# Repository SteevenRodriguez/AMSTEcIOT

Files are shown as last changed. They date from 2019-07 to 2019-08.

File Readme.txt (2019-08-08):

Integrantes: 
•	Nécker Iván Espinosa Feijoo
•	Sophia Denisse Gómez Quimí
•	Steeven Joshua Rodríguez Alvarado
•	Jonathan Oswaldo Yagual Peredo
Título del proyecto: Clasificador de objetos mediante peso
Descripción del proyecto: El clasificador de objetos deberá identificar que objeto está encima de la plataforma, conociendo su peso. Para ello se requiere aplicar machine learning. Esta información debe ser registrada y enviada a la nube para luego ser mostrada por la aplicación desarrollada.

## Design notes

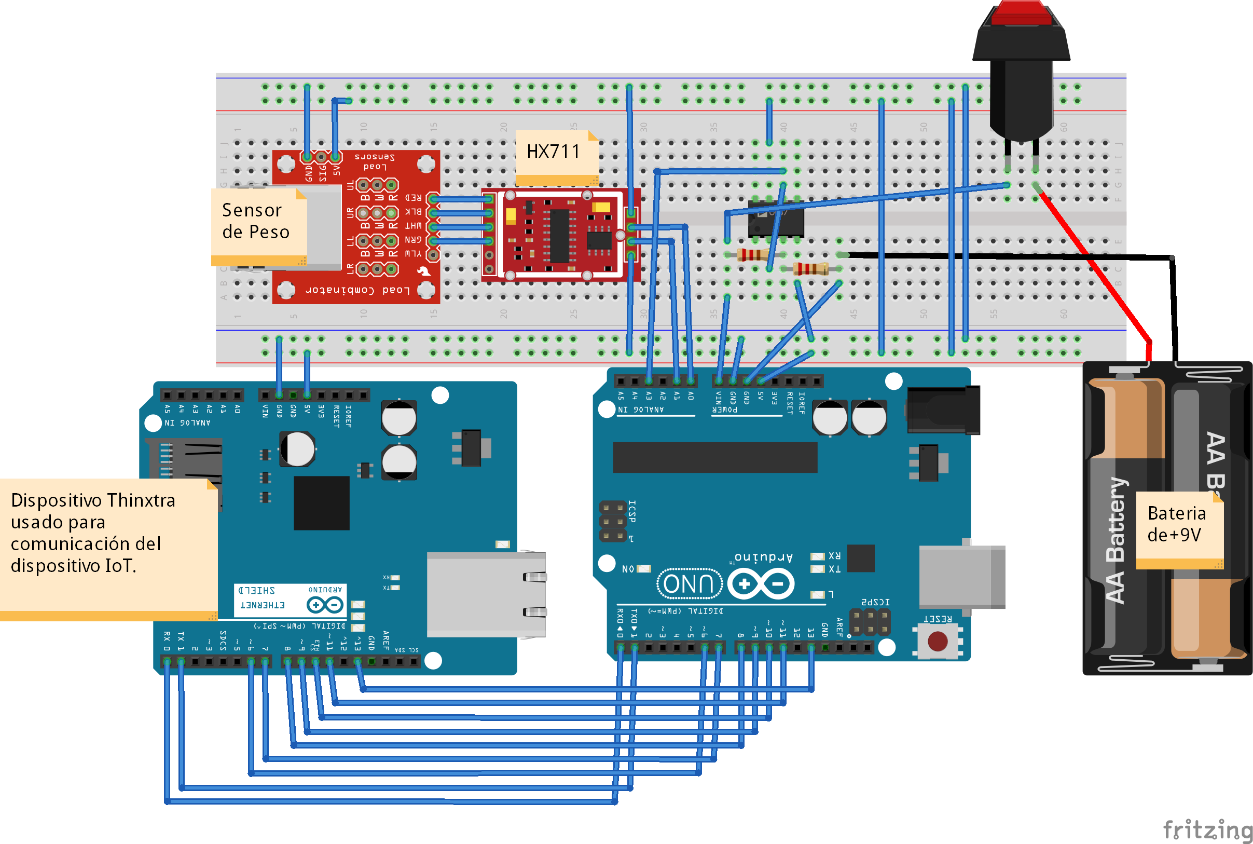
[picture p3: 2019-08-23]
Documentos Entregables/diseño circuito/DiseñoV1_bb.png

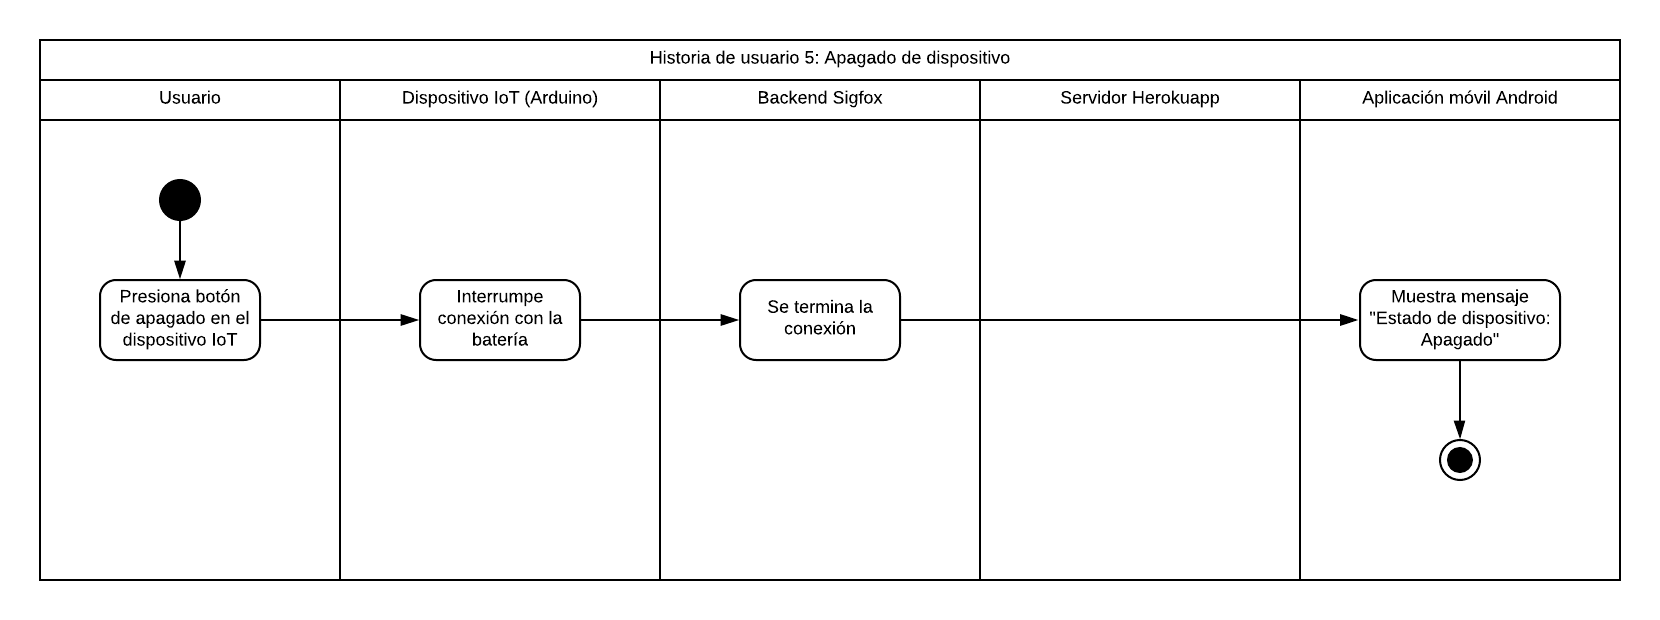
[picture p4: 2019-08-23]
Documentos Entregables/Diagrama de actividades/Diagrama de actividades HU5.png

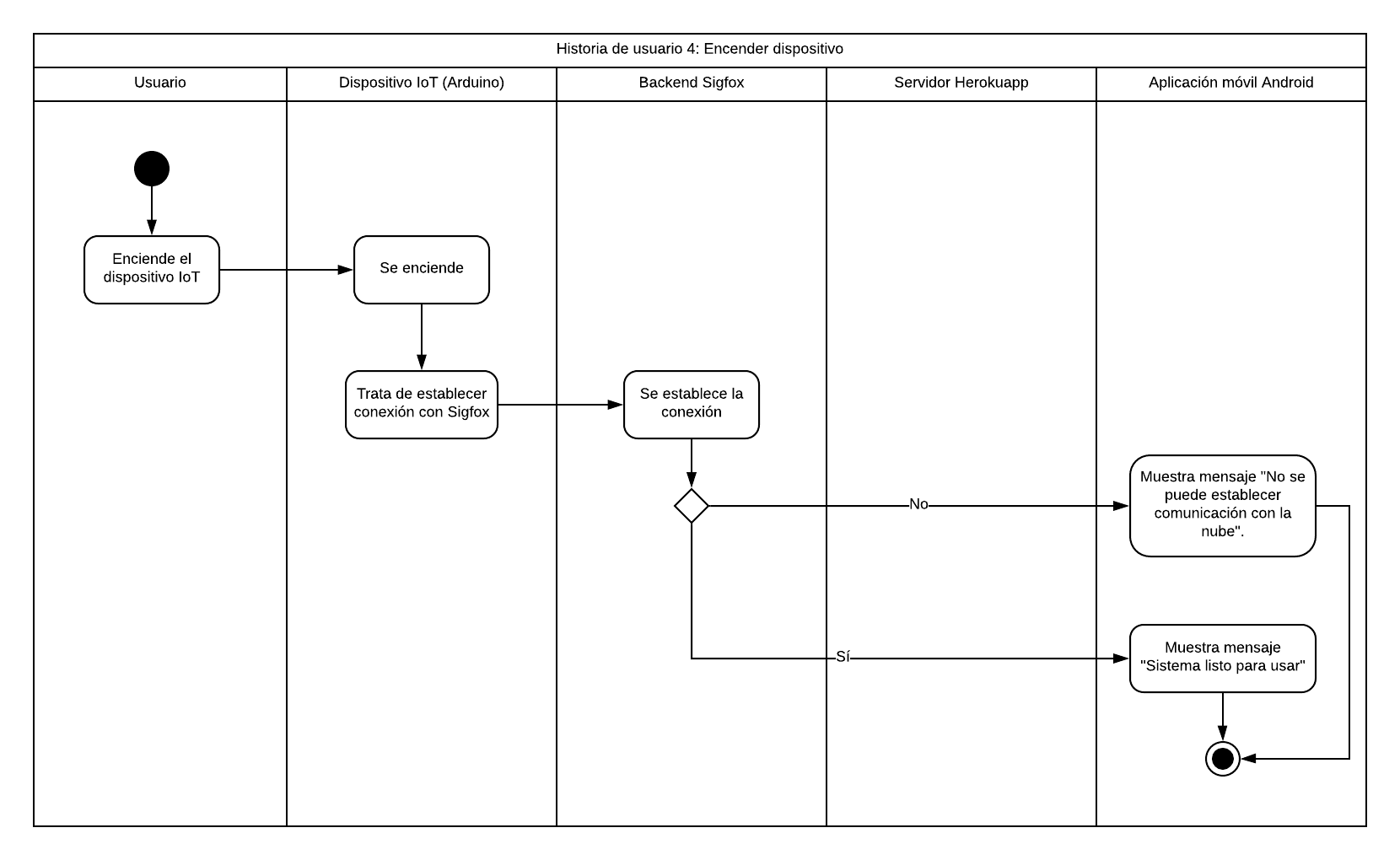
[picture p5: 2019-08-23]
Documentos Entregables/Diagrama de actividades/Diagrama de actividades HU4.png

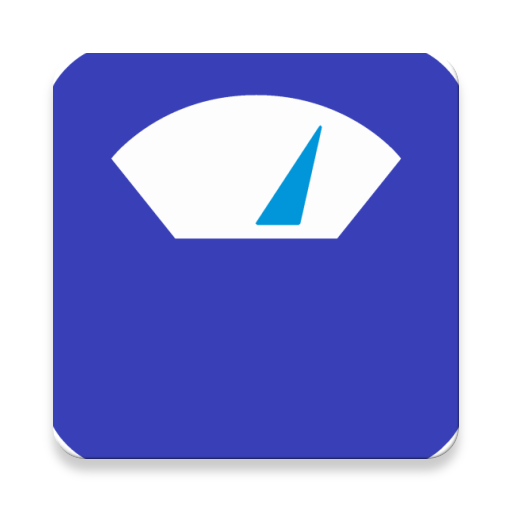
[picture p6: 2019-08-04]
app/src/main/ic_launcher-web.png

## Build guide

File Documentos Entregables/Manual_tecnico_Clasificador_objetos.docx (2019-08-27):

Manual Técnico

GRUPO #6

Tema: Clasificador de objetos mediante peso

Profesora:

- Msig. Adriana Collaguazo Jaramillo

Integrantes:

- Nécker Iván Espinosa Feijoo
- Sophia Denisse Gómez Quimí
- Steeven Joshua Rodríguez Alvarado
- Jonathan Oswaldo Yagual Peredo

Descripción del proyecto

El clasificador de objetos deberá identificar que objeto está encima de la plataforma, conociendo su peso. Para ello se requiere aplicar machine learning. Esta información debe ser registrada y enviada a la nube.

Descripción del problema

La banaera EcIOT busca automatizar la distribución de cajas para ubicarlas en el camión respectivo. Actualmente tienen varios productos y cajas con diferentes tamaños (con variaciones de ± 5g). Las cajas de diferentes tamaños se mueven automáticamente en una cinta transportadora y no se dispone de suficiente tiempo para pesarlas y clasificarlas al mismo tiempo.

Historias de usuarios

- Historia de usuario 1: Consulta

Como usuario puedo clasificar los objetos por su peso respectivo para agilizar el ordenamiento de utensilios.

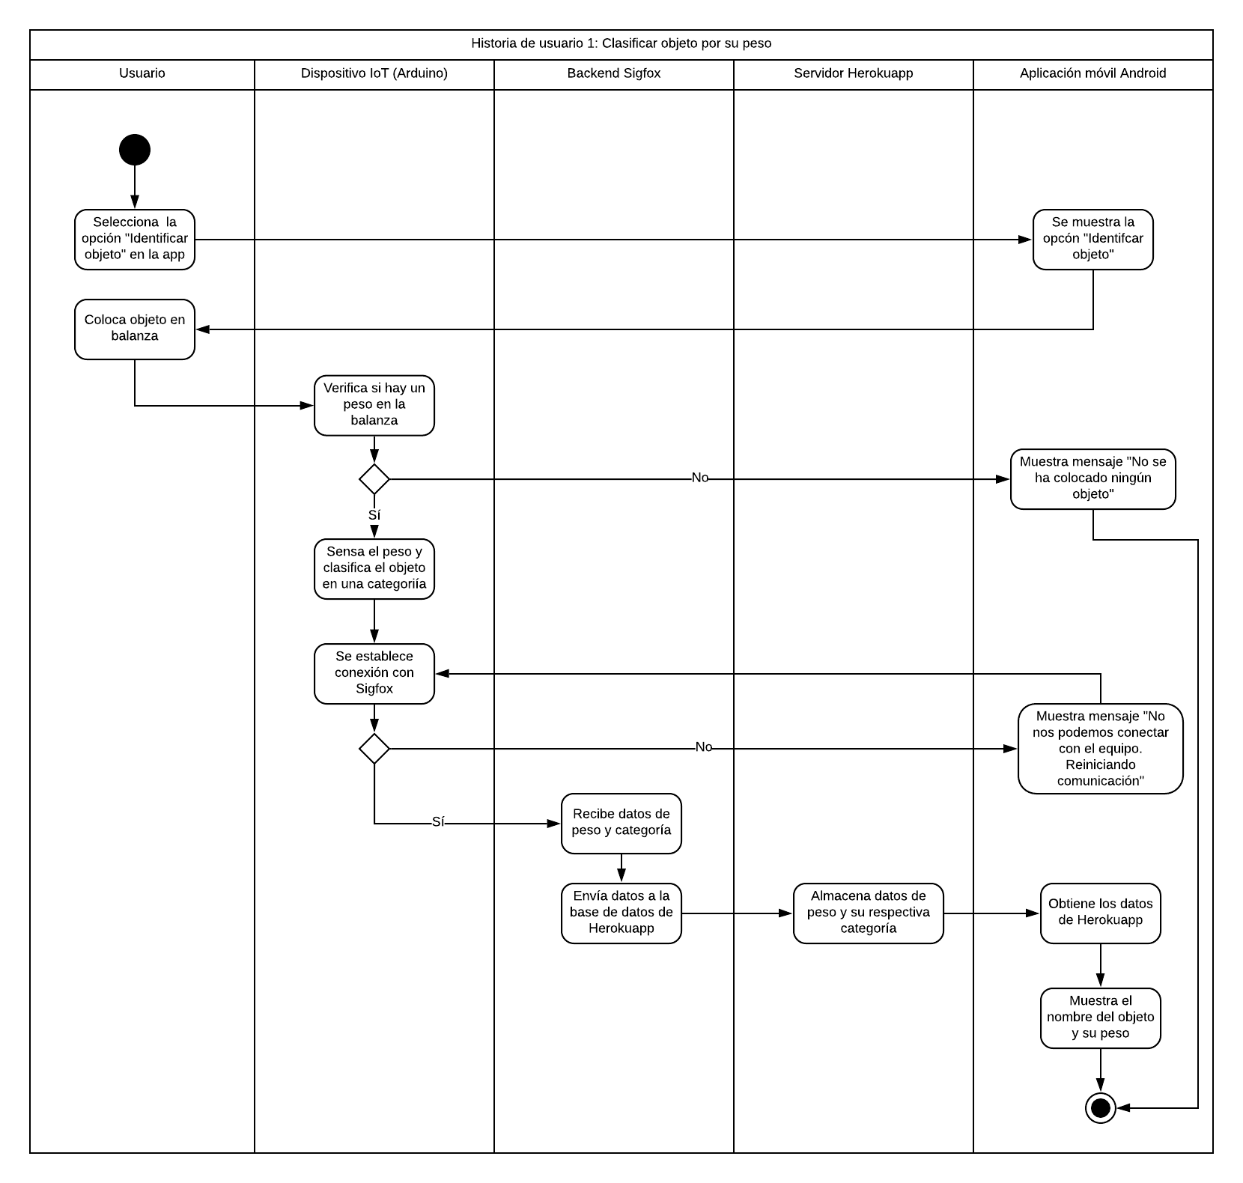
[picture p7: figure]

Figura 1 Historia de usuario 1

- Historia de usuario 2: Reporte

Como usuario puedo entrenar mi clasificador para mejorar el porcentaje de aciertos actual de mi dispositivo.

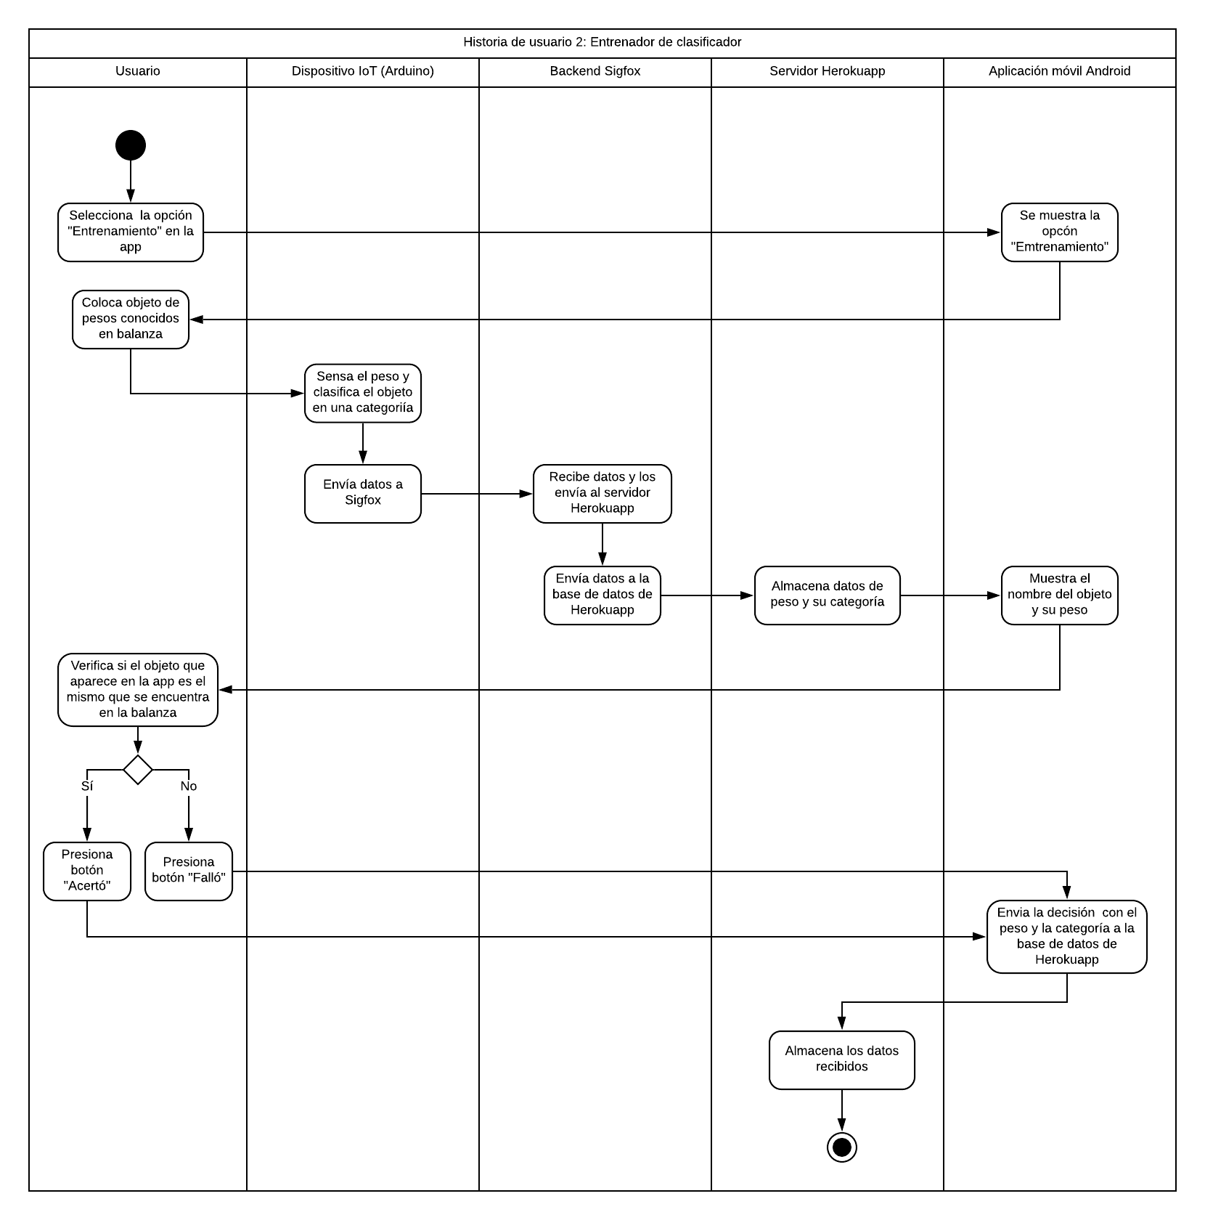
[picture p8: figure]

Figura 2 Historia de usuario 2

- Historia de usuario 3: Loop

Como usuario puedo requiero que la pesa clasificadora este constantemente registrando el nivel de batería (cada 10 minutos) para saber cuándo debería cambiarla.

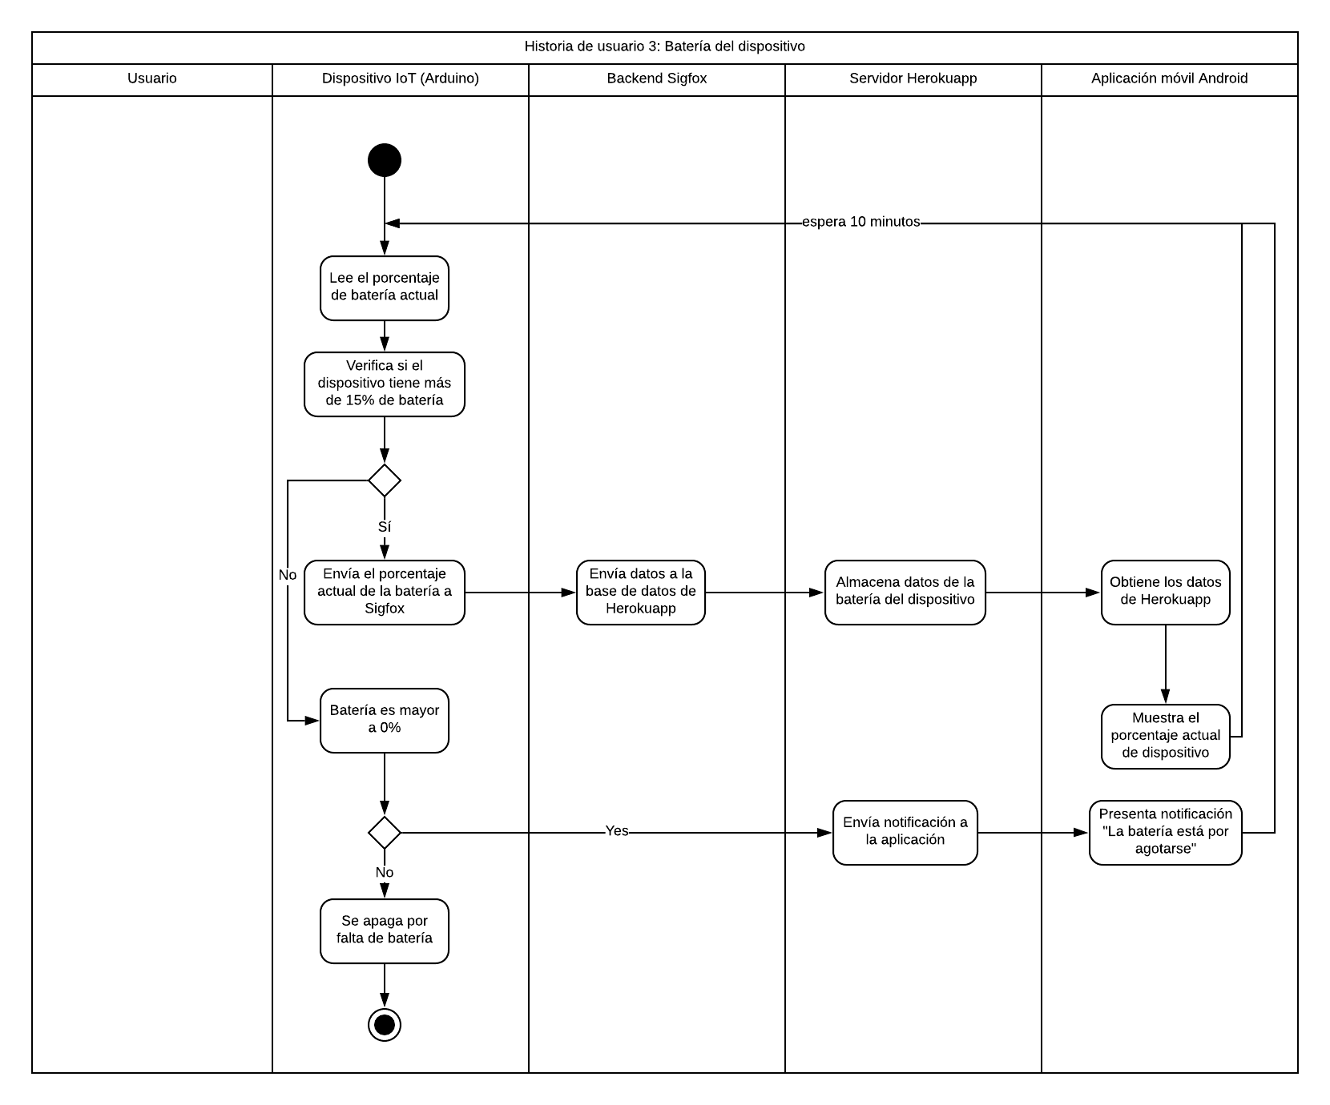
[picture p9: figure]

Figura 3 Historia de usuario 3

- Historia de usuario 4: Start up

Como usuario puedo requiero encender mi dispositivo IoT e iniciar comunicaciones para para comenzar a utilizar el sistema clasificador.

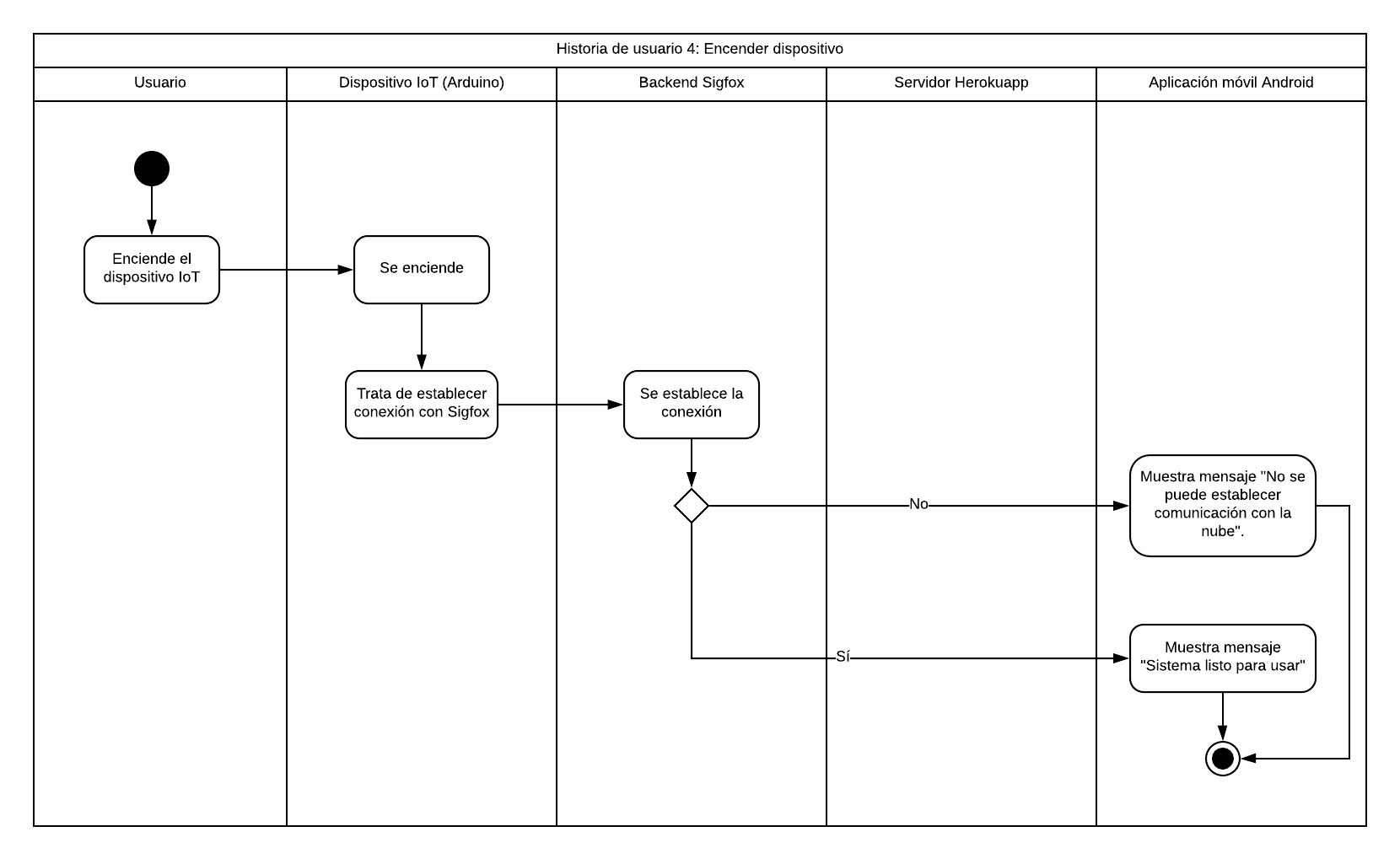
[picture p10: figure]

Figura 4 Historia de usuario 4

- Historia de usuario 5: Shutdown

Como usuario puedo requiero apagar mi dispositivo cuando termine de usarlo para poder ahorrar energía de la batería.


Figura 5 Historia de usuario 5

Diagrama de despliegue

El diagrama de despliegue describe la topología del sistema, la estructura de los elementos de hardware y el software que ejecuta cada uno de ellos.

En este caso los dispositivos que interactúan son:

  - El dispositivo Android que usa la librería Volley para conectarse con el servidor.
  - El servidor que contiene la aplicación web en Python/Django y la base de datos PostgreSQL.
  - El sevidor Sigfox que contiene los módulos encargados de recibir los datos sensados en el dispositivo IoT y enviarlos a almacenar a la base de datos.
  - El dispositiov IoT que se integra con el dispositivo Thinktra para la comunicación con el servidor de Sigfox, y además se encarga de la clasificación de los pesos.

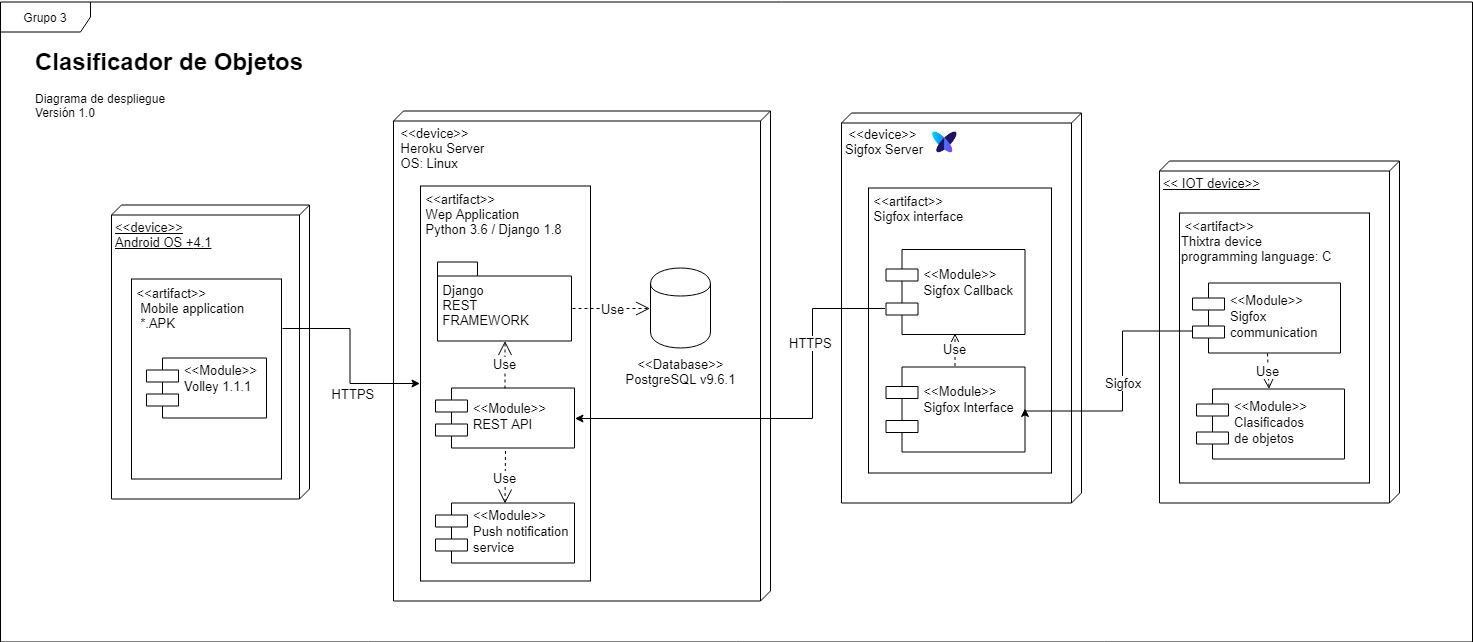
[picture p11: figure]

Figura 6 Diagrama de despliegue

Diagrama de casos de uso

El diagrama de casos de uso es utilizado para especificar la comunicación y el comportamiento de un sistema mediante su interacción con los usuarios u otros sistemas.

En este caso, el actor principal es el usuario que va a usar el sistema clasificador de objeto, este podrá realizar varias actividades que se encuentran especificadas como una opción del menú dentro de la aplicación móvil.

El dispositivo IoT es otro actor dentro del sistema. Este es el encargado de sensar el peso y enviar los datos a sigfox cumple otras funciones que se muestran en la Figura 7.

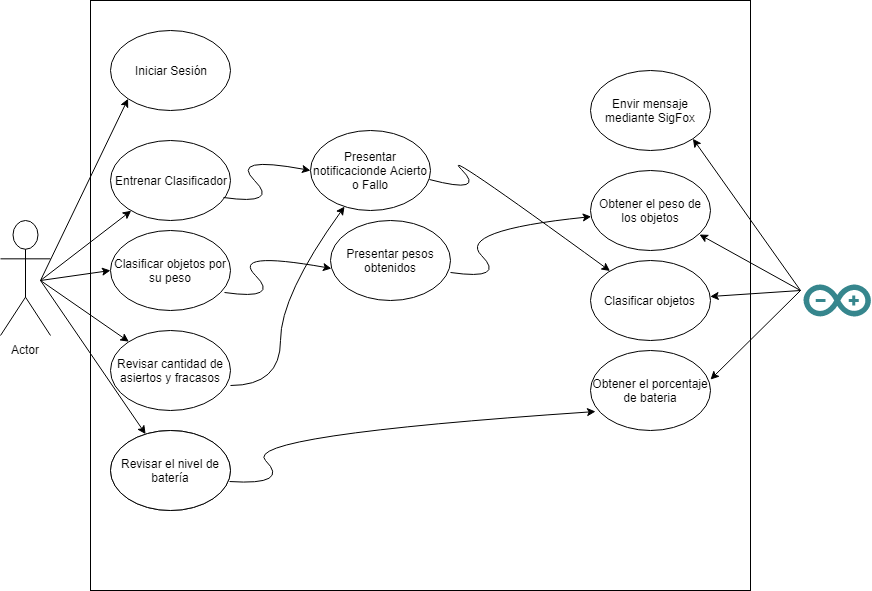
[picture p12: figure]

Figura 7 Diagrama de casos de uso

Diagrama de entidad – relación

El diagrama entidad-relación es una herramienta que se usa para el modelado de datos. En este se pueden ver las relaciones que existen en las tablas.

En la base de Clasificador de objetos se tienen 5 tablas que es donde se almacena el usuario que tiene acceso a la aplicación, el nivel de batería del dispositivo Iot, las categorías y e l peso de los objetos sensados.

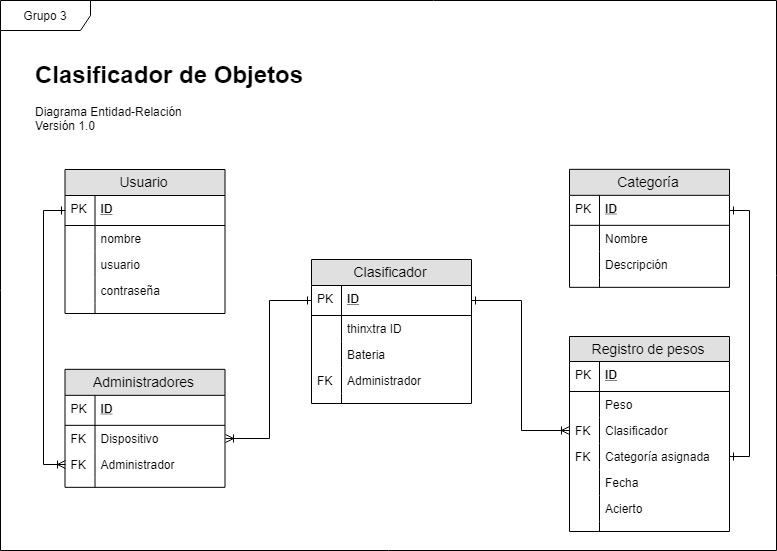
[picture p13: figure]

Figura 8 Diagrama Entidad Relación

Diagrama de clases

Este diagrama describa la estructura del sistema mostrando sus clases, los atributos y métodos que contienen; además, de la relación entre los objetos, como se puede observar en la Figura 9.

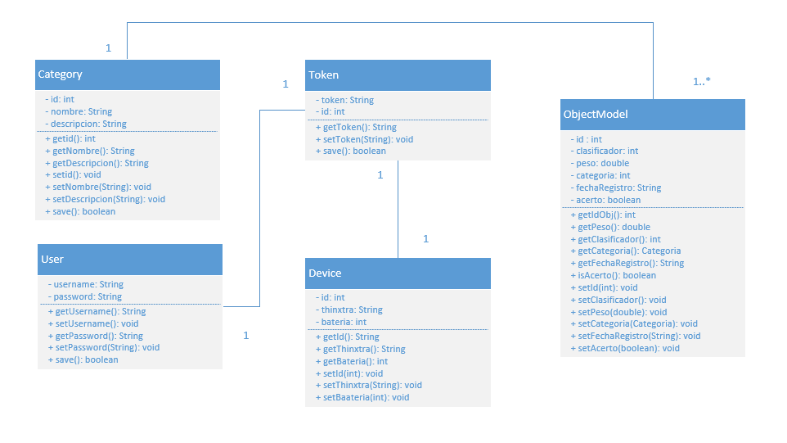
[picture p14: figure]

Figura 9 Diagrama de clases

Diagrama de circuito

El circuito muestra al arduino conectado con el dispositivo Thinxtra que se encarga de enviar lo que se obtiene del sensor al backend de Sigfox para ser almacenados en la base de datos de Herokuapp y luego poder revisarlos en el aplicativo móvil Android.

Por otro lado el arduino se encuentra alimentado a una batería de 9v, en el pin Vin que soporta de 6v a 12v. El nivel de la batería debe ser visualizado dentro de la aplicación móvil, por lo que este nivel debe ingresar en un pin de entrada analógico del arduino, pero debido a que estos pines soportan un máximo de 5v, se realiza un divisor de voltaje con resistencias de igual valor, por lo que se tienen 4.5v que pasan por un seguidor de voltaje para que no afecte el circuito interno del arduino con las resistencias del divisor. Así, en el pin A3 se tiene 4.5v cuando la batería tiene un 100% de carga es decir tiene 9v, así se reduce el voltaje en el pin A3 proporcionalmente al nivel de la batería.

A su vez al arduino va conectado a la celda de carga HX711 que conectado al sensor de peso de 5kg, verifican la deformación del sensor de peso y después de ser calibrado se obtiene el peso del objeto en el sensor.

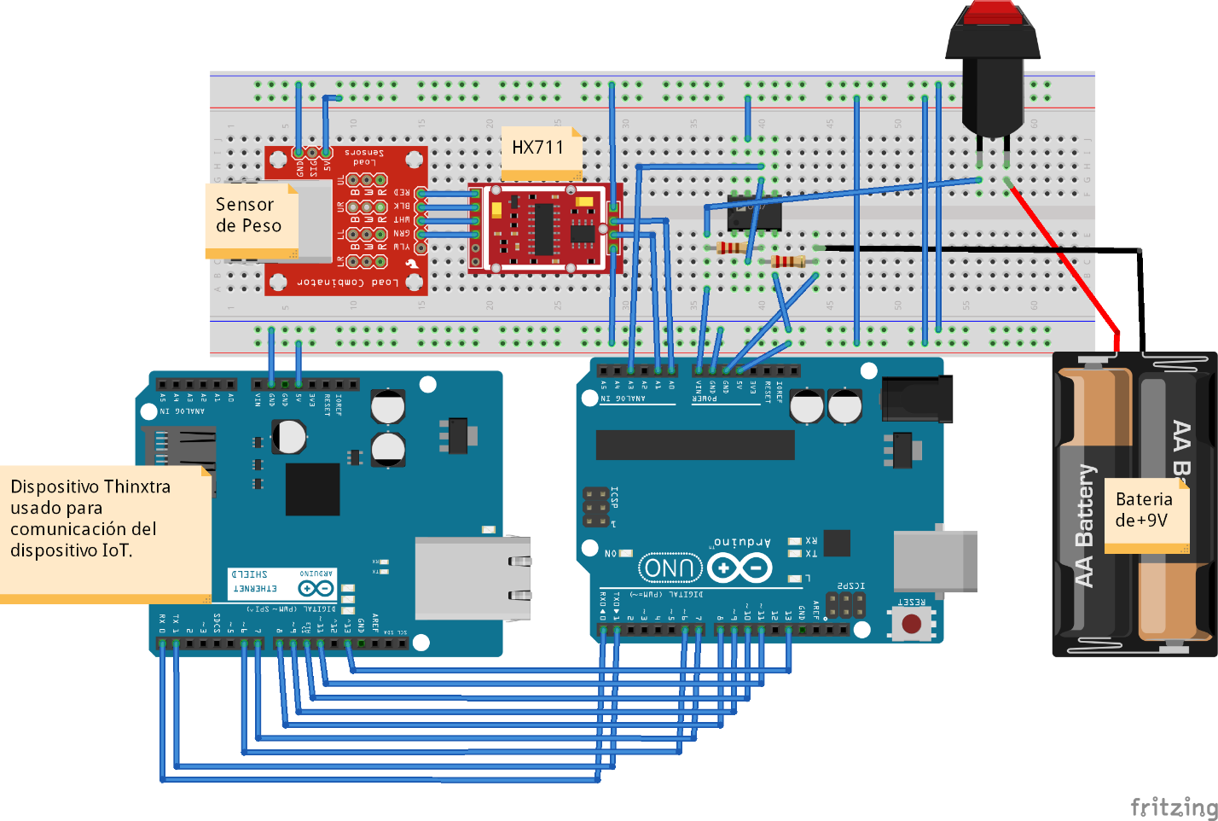
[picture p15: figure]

Figura 10 Diagrama de circuito

Estructura del sistema (código fuente)

- Clase Categoría

Este objeto categoría contiene los atributos id, nombre y descripción que es donde se especifican las categorías que tenemos para el sistema de sensado. Cuenta con sus funciones get y set respectivamente para obtener los atributos del objeto.

public class Category extends RealmObject{
@PrimaryKey
@SerializedName("id")
@Expose
private int id;
@SerializedName("nombre")
@Expose
private String nombre;
@SerializedName("descripcion")
@Expose
private String descripcion;

public int getId() {
return id;
}

public void setId(int id) {
this.id = id;
}

public String getNombre() {
return nombre;
}

public void setNombre(String nombre) {
this.nombre = nombre;
}

public String getDescripcion() {
return descripcion;
}

public void setDescripcion(String descripcion) {
this.descripcion = descripcion;
}

public boolean save() {
boolean isSuccess = true;
Realm realm = Realm.getDefaultInstance();
try {
realm.beginTransaction();
realm.copyToRealmOrUpdate(this);
realm.commitTransaction();
} catch (Exception e) {
e.printStackTrace();
isSuccess = false;
} finally {
realm.close();
}

return isSuccess;
}


}

- Clase Object Model (objeto sensado)

Este objeto Object Model se refiere a los objetos que se sensan. Esta clase tiene los atributos del registro de peso y el id de clasificador se refiere a la categoría a la que pertenece el objeto. Cuenta con sus funciones get y set respectivamente para obtener los atributos del objeto.

public class ObjectModel extends RealmObject {
@PrimaryKey
@SerializedName("id")
@Expose(serialize = false)
private int id;
@SerializedName("clasificador")
@Expose
private int clasificador;
@SerializedName("categoria")
@Expose
private int categoria;
@SerializedName("fecha_registro")
@Expose
private String fechaRegistro;
@SerializedName("peso")
@Expose
private double peso;
@SerializedName("acerto")
@Expose
private boolean acerto;

public int getId() {
return id;
}

public void setId(int id) {
this.id = id;
}

public int getClasificador() {
return clasificador;
}

public void setClasificador(int clasificador) {
this.clasificador = clasificador;
}

public int getCategoria() {
return categoria;
}

public void setCategoria(int categoria) {
this.categoria = categoria;
}

public String getFechaRegistro() {
return fechaRegistro;
}

public void setFechaRegistro(String fechaRegistro) {
this.fechaRegistro = fechaRegistro;
}

public double getPeso() {
return peso;
}

public void setPeso(double peso) {
this.peso = peso;
}

public boolean isAcerto() {
return acerto;
}

public void setAcerto(boolean acerto) {
this.acerto = acerto;
}
}

- Clase User

Este objeto User contiene los atributos username y password. Este objeto se inicializa con el usuario y contraseña que inicia sesión. Cuenta con sus funciones get y set respectivamente para obtener los atributos del objeto.

public class User extends RealmObject {

private String username;

private String password;


public User() {
}

public User(String username, String password) {
this.username = username;
this.password = password;
}

public String getUsername() {
return username;
}

public void setUsername(String username) {
this.username = username;
}

public String getPassword() {
return password;
}

public void setPassword(String password) {
this.password = password;
}

public boolean save() {
boolean isSuccess = true;
Realm realm = Realm.getDefaultInstance();
try {
realm.beginTransaction();
realm.copyToRealmOrUpdate(this);
realm.commitTransaction();
} catch (Exception e) {
e.printStackTrace();
isSuccess = false;
} finally {
realm.close();
}

return isSuccess;
}
}

- Clase Token

Este objeto Token contiene los atributos id y token. Este objeto es el token con que se puede realizar los requerimientos http al servidor de Herokuapp.

public class Token extends RealmObject {
@PrimaryKey
private int id;

@SerializedName("token")
@Expose
private String token;
public Token(){
this.id = new Date().hashCode();
}

public Token(String token) {
this.id = new Date().hashCode();
this.token = token;
}
public String getToken() {
return token;
}

public void setToken(String token) {
this.token = token;
}

public boolean save() {
boolean isSuccess = true;
Realm realm = Realm.getDefaultInstance();
try {
realm.beginTransaction();
realm.copyToRealmOrUpdate(this);
realm.commitTransaction();
} catch (Exception e) {
e.printStackTrace();
isSuccess = false;
} finally {
realm.close();
}

return isSuccess;
}

}

- Clase Device

Este objeto Device contiene los datos del dispositivo con el nivel de batería que tiene el arduino. Cuenta con sus funciones get y set respectivamente para obtener los atributos del objeto.

public class Device extends RealmObject {
@PrimaryKey
@SerializedName("id")
@Expose
private int id;
@SerializedName("thinxtra")
@Expose
private String thinxtra;
@SerializedName("bateria")
@Expose
private int bateria;

public int getId() {
return id;
}

public void setId(int id) {
this.id = id;
}

public String getThinxtra() {
return thinxtra;
}

public void setThinxtra(String thinxtra) {
this.thinxtra = thinxtra;
}

public int getBateria() {
return bateria;
}

public void setBateria(int bateria) {
this.bateria = bateria;
}

}

Recursos de hardware/software para usuario final de proyecto

- Hardware:
  - Dispositivo móvil Android

Dispositivo | Precio
Dispositivo Arduino | $ 10.50
Kit Thinxtra DEV (incluido envío) | $ 143.87
Sensores de peso | $ 7
Conversores de peso HX711 | $ 3.95
Total | $ 165.32

- Software:
  - Sistema operativo Android v.8 o superior
  - Base de datos Postgre V9.6.1

Recursos de hardware/software para desarrollo

- Hardware:
  - Dispositivo Arduino
  - Kit Thinktra DEV
  - Sensores de peso
  - Conversores de peso HX711
  - Computadora con 8Gb de ram (mínimo 2Gb) y espacio libre de 4 Gb.
- Software:
  - Android Studio
  - Java 8
  - Base de datos Postgre V9.6.1

Fotografías del prototipo

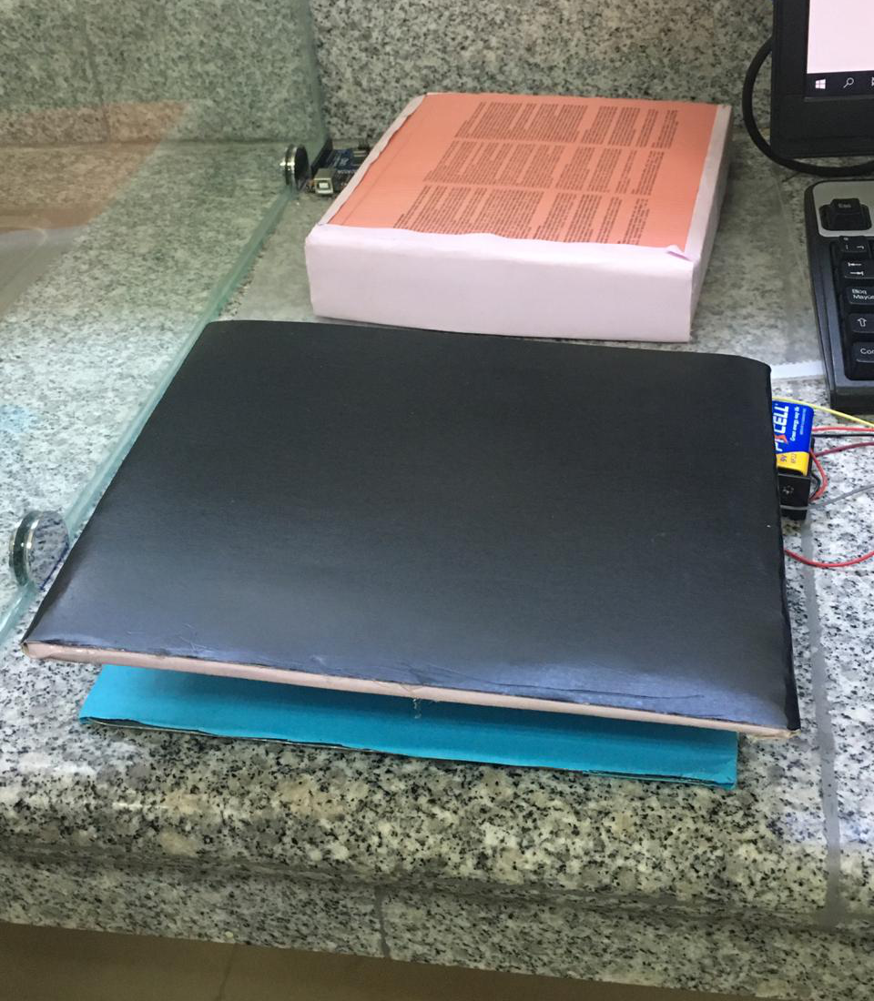
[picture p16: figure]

Figura 11 Prototipo final

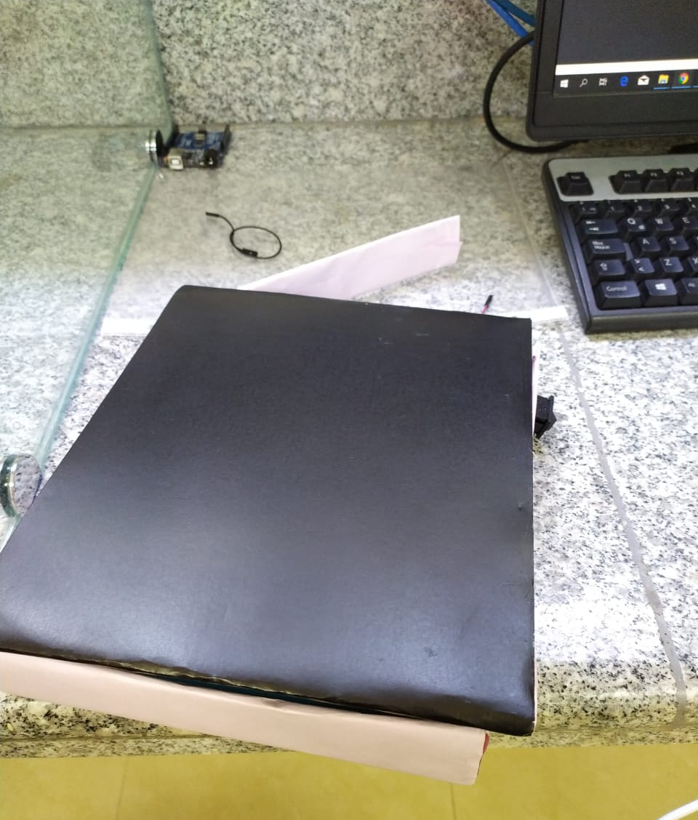
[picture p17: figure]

Figura 12 Prototipo final con el interruptor de encendido

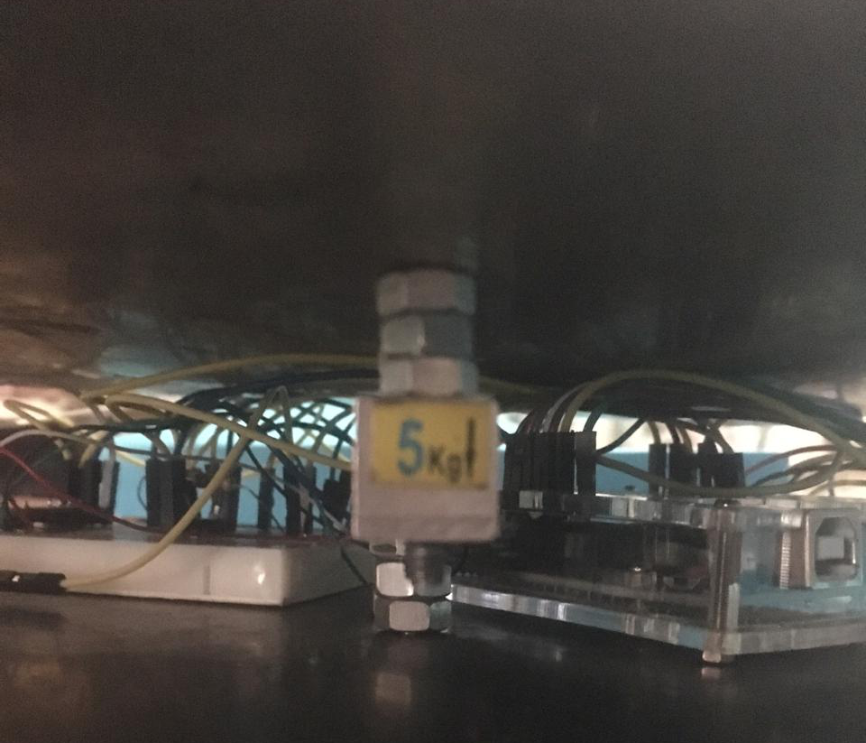
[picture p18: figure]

Figura 13 Sensor ubicado en el interior de la balanza

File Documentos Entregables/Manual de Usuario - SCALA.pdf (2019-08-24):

# Manual de

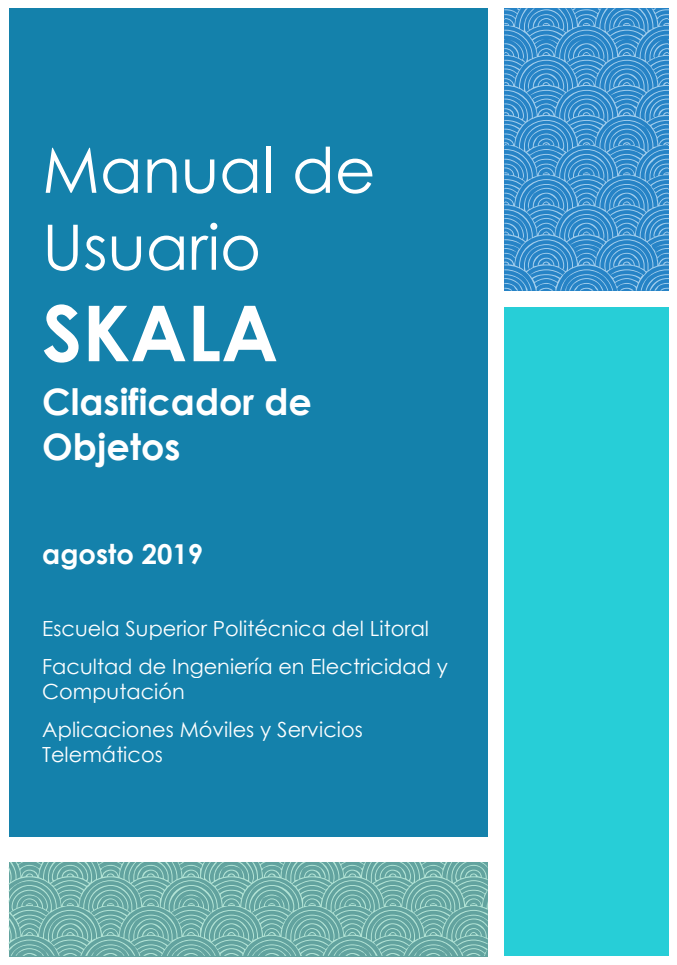
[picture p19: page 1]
Usuario SKALA; Clasificador de Objetos; agosto 2019

Escuela Superior Politécnica del Litoral
Facultad de Ingeniería en Electricidad y
Computación
Aplicaciones Móviles y Servicios
Telemáticos

# Tabla de contenido

## I. Instalación | 1

## APK

## Verificar instalación

II. | Inicio de Sesión | 3
III. | Encender dispositivo IoT | 4
IV. | Pantalla principal | 4
| Estado de Batería

## V. Menú | 5

| Entrenamiento
| Ver Histórico
| Cerrar Sesión

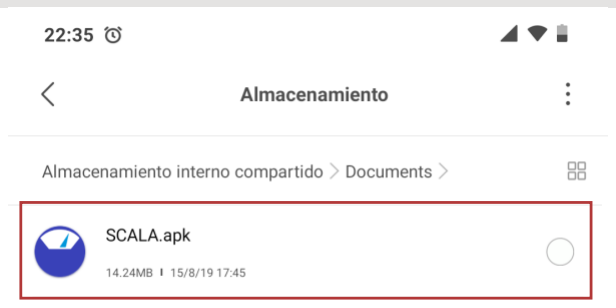
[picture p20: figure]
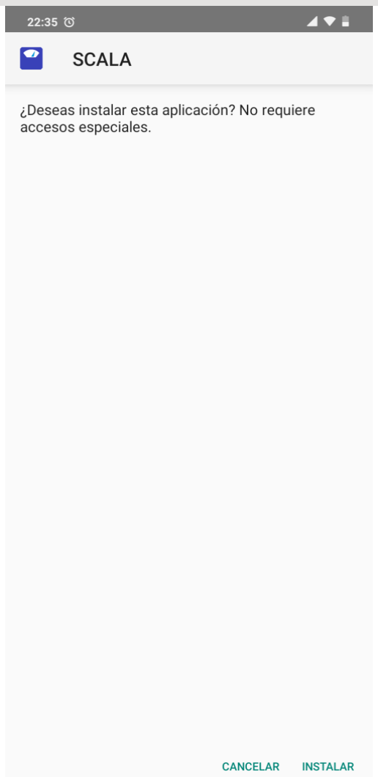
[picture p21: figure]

SCALA – CLASIFICADOR DE OBJETOS | 1

# Instalación

## APK

El desarrolador proveerá el APK para instalar la aplicación, localícela en la memoria de su dispositivo y haga click sobre ésta.

El desarrolador proveerá el APK para instalar la aplicación, localícela en la memoria de su dispositivo y haga click sobre ésta.

## Verificar instalación

Verificar que la aplicación se encuentra instalada accediendo al menú de aplicaciones del celular.

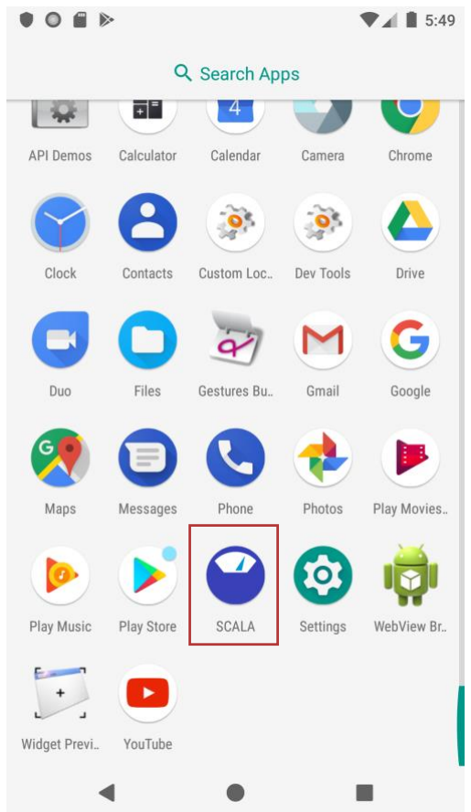
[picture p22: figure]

# Inicio de Sesión

Luego de verificar la instalación de la aplicación se procede a ejecutarla presionando sobre el icono de la misma.

Se desplegará la pantalla de inicio de sesión en donde deberá ingresar su usuario y contraseña para acceder a las funcionalidades de la app.

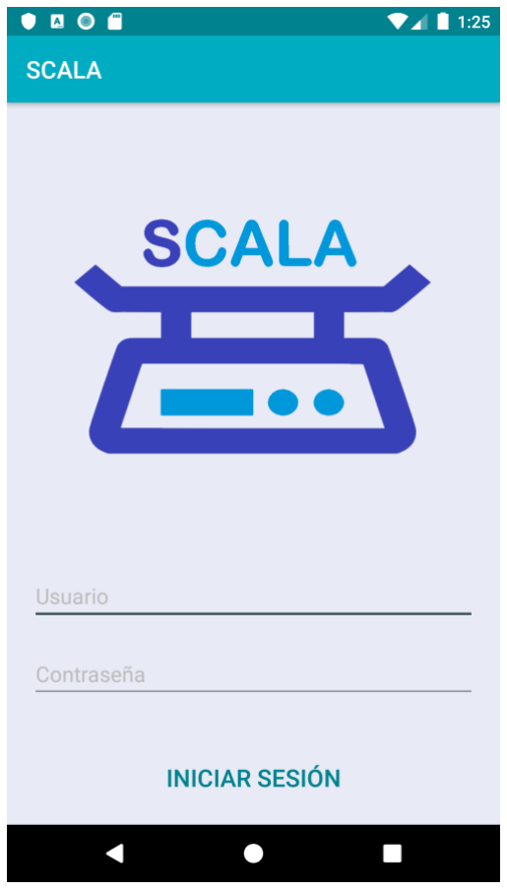
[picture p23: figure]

Consultar las credenciales de inicio de sesión con el proveedor de la aplicación

# Encender dispositivo IoT

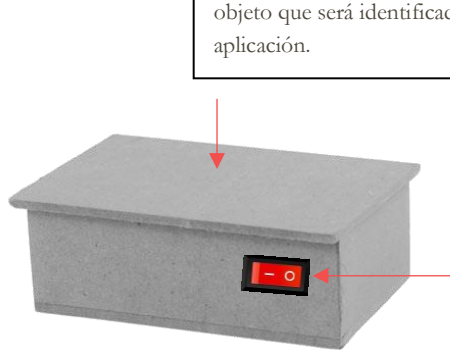
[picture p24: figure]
aplicación.

Una vez que el usuario encienda el dispositivo, el sistema estará listo para censar objetos.

# Pantalla principal

Plataforma. - Aquí el usuario deberá colocar el objeto que será identificado y mostrado en la

Botón Encendido/Apagado.
– Presione para encender o apagar el dispositivo.

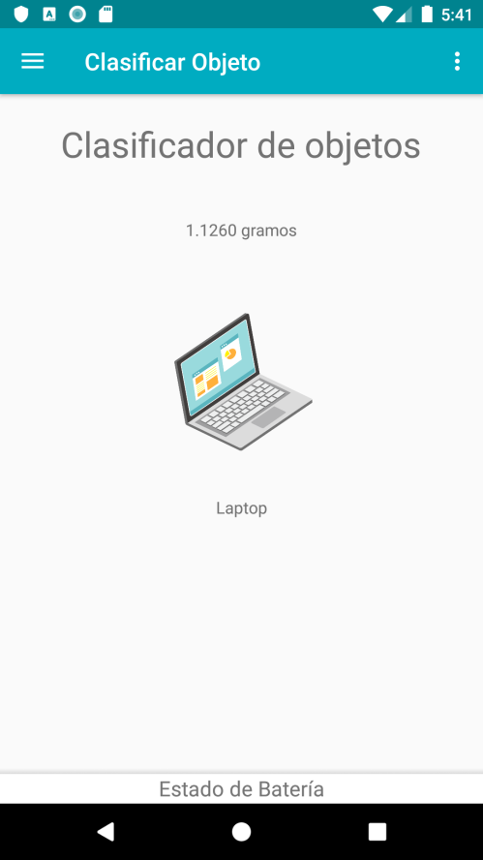
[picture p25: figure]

Una vez ingresadas las credenciales de inicio de sesión la app mostrará el último objeto censado por la balanza, esta pantalla se irá actualizando en tiempo real siempre y cuando el usuario haya colocado algún objeto en la balanza.

## Estado de Batería

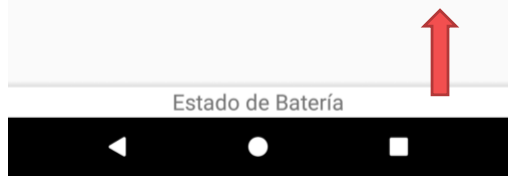
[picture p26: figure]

En esta pantalla el usuario tiene la opción de consultar el porcentaje de carga de la batería que alimenta el circuito identificador de objetos mediante la pestaña ESTADO DE BATERÍA ubicado en la parte inferior.

Para acceder a esta opción el usuario debe desplazar su dedo hacia arriba desde la pestaña

# Menú

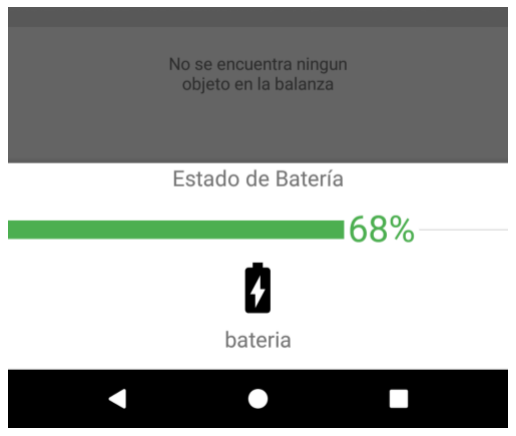
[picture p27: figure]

Para acceder al menú con las distintitas opciones que tiene la aplicación, debe hacer clic en ícono ubicado en la esquina superior izquierda

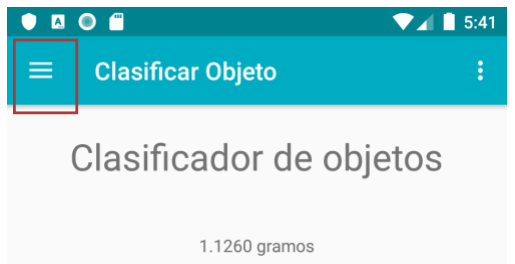
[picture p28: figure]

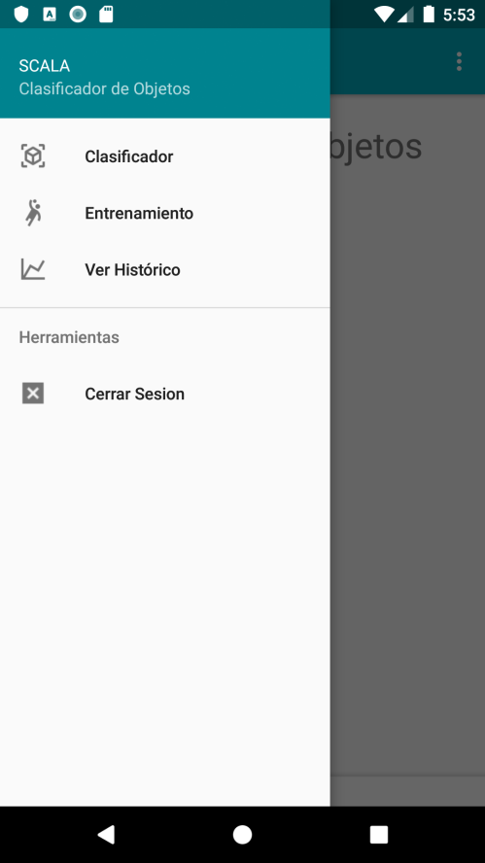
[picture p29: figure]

El menú consta de 4 diferentes opciones: Clasificador (pantalla principal), Entrenamiento, Ver Histórico y Cerrar Sesión.

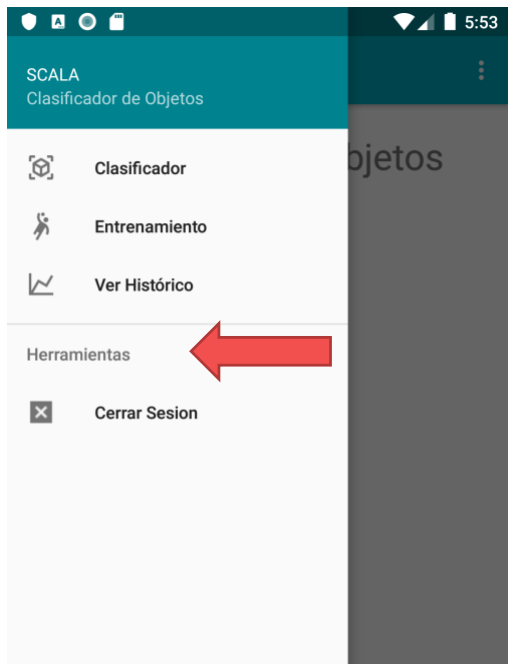
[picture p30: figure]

En caso de que no requiera regresar a la pantalla sobre la que se encontraba, se debe desplazar el dedo hacia la izquierda, cerrando el menú mostrado.

## Entrenamiento

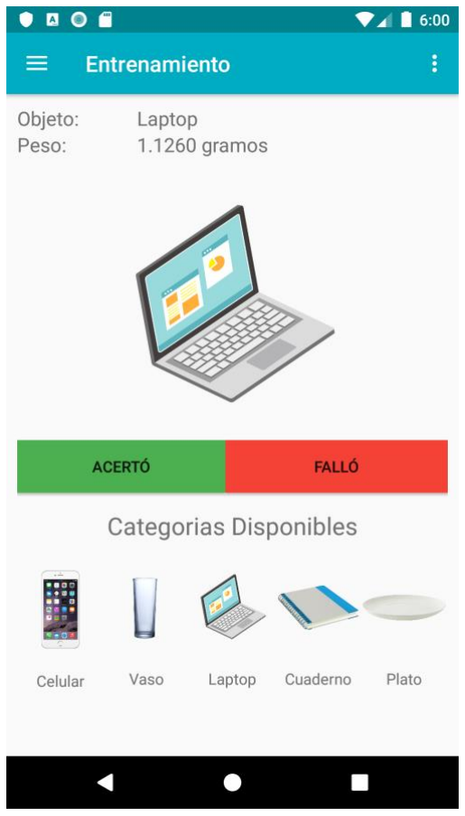
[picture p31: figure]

Esta pantalla muestra el último objeto censado, indicando su categoría y peso

Adicional, se muestran las categorías disponibles que puede identificar la balanza.

Se puede dar el caso que la aplicación muestre un objeto que no corresponde al censado por la balanza.

A fin de que la aplicación implemente machine learning, el usuario dispone de la opción de indicar si el último objeto censado corresponde a la categoría mostrada en la aplicación haciendo uso de los botones ACERTÓ y FALLÓ.

## Ver Histórico

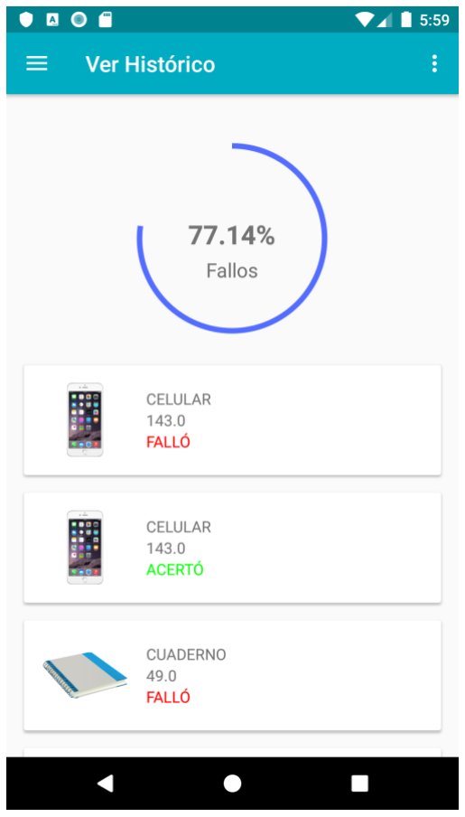
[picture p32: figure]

La pantalla Histórico muestra un listado de todos los elementos registrados en la base de datos indicando su categoría, peso y si el objeto pesado fue el mostrado por la aplicación.

También se muestra un gráfico estadístico que muestra el porcentaje de errores que ha tenido la aplicación al momento de identificar objetos.

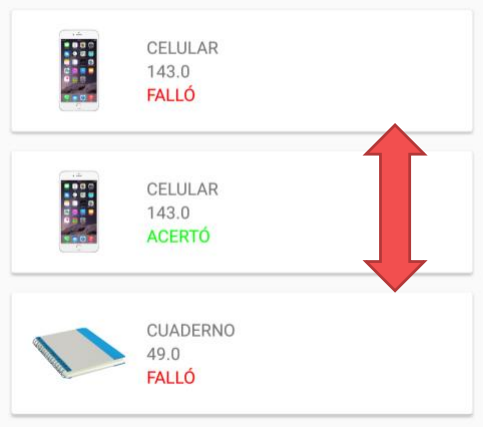
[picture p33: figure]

Debido a la extensión de la base de datos, el usuario puede realizar un gesto de desplazamiento para observar todos los elementos de la lista.

## Cerrar Sesión

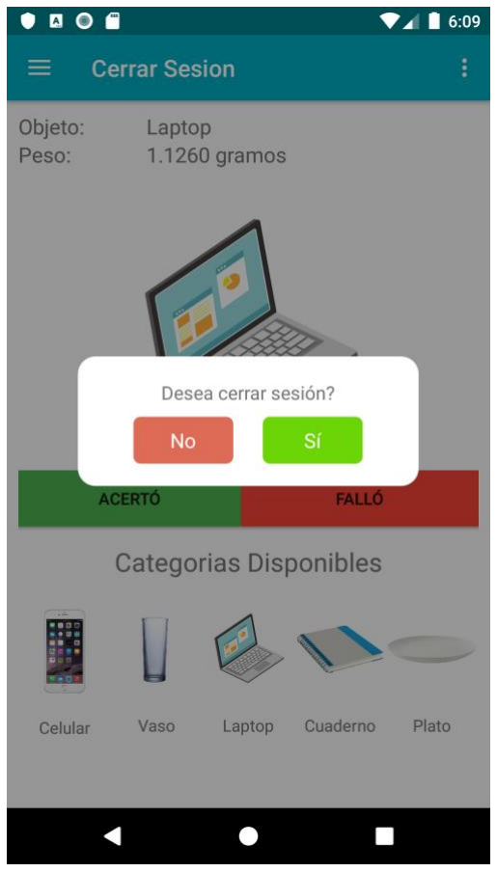
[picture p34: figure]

Cuando el usuario presiona la opción de cerrar sesión desde el menú, se desplegará un diálogo de confirmación.

El usuario debe presionar SÍ para cerrar la sesión o NO para regresar a la aplicación.

Cuando el usuario cierre sesión automáticamente se redirigirá a la pantalla de inicio de sesión.

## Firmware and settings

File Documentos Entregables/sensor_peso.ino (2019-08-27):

#include <WISOL.h>
#include <Wire.h>
#include <math.h>
#include "HX711.h"

// definimos variables de entrada
#define DOUT  A1
#define CLK  A0
#define ANALOGPILA A3


Isigfox *Isigfox = new WISOL();
typedef union{
uint16_t number;
uint8_t bytes[2];
} UINT16_t;

//se instacia el metodo de la clase
HX711 balanza(DOUT, CLK);

// se declara variables globales para obtener la bateria
int analogValor = 0; // variable para contar el tiempo de envio de bateria
float previousMillis = 0;     // variable para setear el inicio del tiempo   
float intervaloMaximo = 60000; // variable para setear el máximo tiempo 
int voltaje = 0;		// variable para obtener el voltaje de la bateria
int porcentaje_voltaje=0;       // variable para obtener el porcentaje de bateria
boolean tiempo = false;		// variable
float volt=0;

// variables globales del proceso 
float peso; // para obtener el peso
int categoria; // setear categoria
int bateria;   // para obtener el porcentaje de bateria
float peso_anterior=0;
float notificacion= 0;

// se inicializa las variables
void setup() {
  Wire.begin();
  Wire.setClock(100000);
  Serial.begin(9600);
  

  // WISOL modem test
  Isigfox->initSigfox();
  Isigfox->testComms();
  //Serial.println(balanza.read());
  Serial.print("Lectura del valor del ADC:  ");
  Serial.println(balanza.read());
  Serial.println("No ponga ningun  objeto sobre la balanza");
  Serial.println("Destarando...");
  Serial.println("...");
  balanza.set_scale(439430.25);
  balanza.tare(20);  //Reset the scale to 0
  Serial.println("Listo para pesar"); 

 
}

void loop() {
  peso = obtenerPeso();  
  bateria = obtener_porcentaje_bateria();
  categoria =  obtenerCategoria(peso);
  Serial.print("Peso: ");
  Serial.print(peso);
  Serial.println(" kg"); 
  
  Serial.print("Categoria: ");
  Serial.println(categoria);
  
  if ((peso <= peso_anterior-0.01) or (peso >= peso_anterior+0.01)){ 
    byte *float_byte = (byte *)&peso;
    byte *float_byte2 = (byte *)&categoria;
	byte *float_byte3 = (byte *)&bateria;
    const uint8_t payloadSize = 9;
    uint8_t buf_str[payloadSize];
    
    buf_str[0] = float_byte3[0];
    buf_str[1] = float_byte3[1];
    buf_str[2] = float_byte[0];
    buf_str[3] = float_byte[1];
    buf_str[4] = float_byte[2];
    buf_str[5] = float_byte[3];
    buf_str[6] = float_byte2[0];
    buf_str[7] = float_byte2[1];
  
    Send_Pload(buf_str, payloadSize);
    Serial.println("_Se envia");
    //delay(20000);
  }
  peso_anterior=peso;

  tiempo = retardo();
  if (tiempo==true){
          
		envio_porcentaje();
  } 
 }

// funcion para obtener el peso del objeto colocado en la balanza
float obtenerPeso(){
  //Serial.print("Peso: ");
  float peso1 ;
  peso1 = (balanza.get_units(20)*-1);
  //Serial.println(" kg");
  delay(500);

  if (peso1 < 0){
    peso1 = 0;
  }
  
  return peso1;
}

// funcion para obtener la categoria de acuerdo a un perfil
int obtenerCategoria(float peso){
  int categoria;
  
  if (peso <= 0.01){
    categoria = 11;//nada en la balanza
    }
  else if (peso >= 0.12 and peso< 0.174){
    categoria = 2;//celular
    }
    else if (peso>= 0.290 and peso <= 0.35){
      categoria = 7;//vaso
    }
    else if ((peso>= 0.225 and peso <= 0.275) or (peso>= 0.35 and peso <= 0.38)){
      categoria = 9;//plato
    }
    else if (peso>= 1.5 and peso <= 2.8){
      categoria =8;//laptop
    }
    else if (peso>= 0.41 and peso <= 0.58){
  categoria =5;//cuaderno
    }
    else{
        categoria =10;//desconocido
    }
    return categoria;
}

// funcion para el envio de datos a sigfox
  void Send_Pload(uint8_t *sendData, int len) {
    recvMsg *RecvMsg;
    RecvMsg = (recvMsg *)malloc(sizeof(recvMsg));
    Isigfox->sendPayload(sendData, len, 0, RecvMsg);
    for (int i = 0; i < RecvMsg->len; i++) {
      Serial.print(RecvMsg->inData[i]); 
    }
    Serial.println("");
    free(RecvMsg);
}

// funcion para cintabilizar el tiempo

boolean retardo(){
      float currentMillis = millis();
      if(currentMillis - previousMillis > intervaloMaximo) {  //Cuando se cumplen los 10 minutos
            previousMillis = currentMillis;   
            return true; 
      }else{
         return false;
      }
  }

// funcion para obtener el porcentaje de bateria
 int obtener_porcentaje_bateria(){
    analogValor = analogRead(ANALOGPILA); 
    // Obtenemos el voltaje
    voltaje = int(0.0048 * analogValor);
    porcentaje_voltaje = int (voltaje * 22.22); 
    Serial.print("Voltaje: ");
    Serial.println(voltaje);
    Serial.print("Porcentaje Voltaje: ");
    Serial.println(porcentaje_voltaje);
    return porcentaje_voltaje;
 }

// funcion para enviar el porcentaje de bateria al backend de sigfox
 void envio_porcentaje(){
    volt = int (obtener_porcentaje_bateria());
    byte *float_byte = (byte *)&volt;
    const uint8_t payloadSize = 3;
    uint8_t buf_str[payloadSize];
    buf_str[0] = float_byte[0];
    buf_str[1] = float_byte[1];
  
    Send_Pload(buf_str, payloadSize);
    Serial.println("_Se envia bateria");
 }

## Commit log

2019-06-12 Update strings.xml
    paramtrizar las variables para inicio de sesion
2019-06-12 Update activity_main.xml
    Se añade el código del archivo Activity_main.xml para la ventana de inicio de sesion.
2019-06-14 [ADD] Menu con opciones y nivel de bateria
    [app_bar_drawer_menu.xml]
2019-06-14 Creación de clase para manipular base de datos SQLite
2019-06-14 Creación de función iniciarSesion y una ventana Menu, por ahora en blanco, que aparece luego de que el usuario inicia sesión.
2019-06-14 [UPD] Inicio de sesion
2019-06-14 [UPD] Color del porcentaje de la bateria
2019-06-14 Diagramas de flujos de historias de usuario
2019-06-14 Diagrama del circuito
2019-06-14 [UPD] Merge de Actividades en Sprint 1
2019-06-21 Add files via upload
    Diseño del circuito a usar.
    [DiseñoV1.fzz]
2019-07-12 XML del entrenador de objetos
2019-07-19 Modificacion de identificar objeto
2019-07-19 Actualizacion de identificar objeto
2019-07-19 [UPD] Refactorizacion de proyecto
    [app_bar_drawer_menu.xml]
2019-07-19 [UPD] Refactor de request
2019-07-22 Diseño y cambio de categorias
2019-07-25 [ADD] Ultimo Registro, cambio de imagenes a mas pequenas
2019-08-04 Ícono y nombre de aplicación, Pantalla de inicio, Logo, Colores temporales
2019-08-06 Cambios en pantalla de inicio de sesión e íconos del drawer menu
2019-08-07 Cambio de imágenes de categorías y color de botoness en pantalla entrenamiento
2019-08-15 Cerrar diálogo de inicio de sesión y al actualizar el hilo
2019-08-16 Create Diagrama de actividades
2019-08-16 Diagramas de actividades Corregido
2019-08-16 Add files via upload
    Diseño del circuito
2019-08-16 Manual de Usuario
2019-08-23 Cambio de nombres de paquete para su publicación en la Playstore
2019-08-24 Clasificador de Objetos - VIDEO
2019-08-24 Manual de Usuario FINAL
2019-08-27 Add files via upload
    Se adjunta codigo de arduino para obtener el peso del objeto colocado en la balanza, obtener el porcentaje de bateria y enviar al backend de sigfox.
